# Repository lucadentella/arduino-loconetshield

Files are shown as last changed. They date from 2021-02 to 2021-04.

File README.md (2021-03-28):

# Loconet Shield / Interface
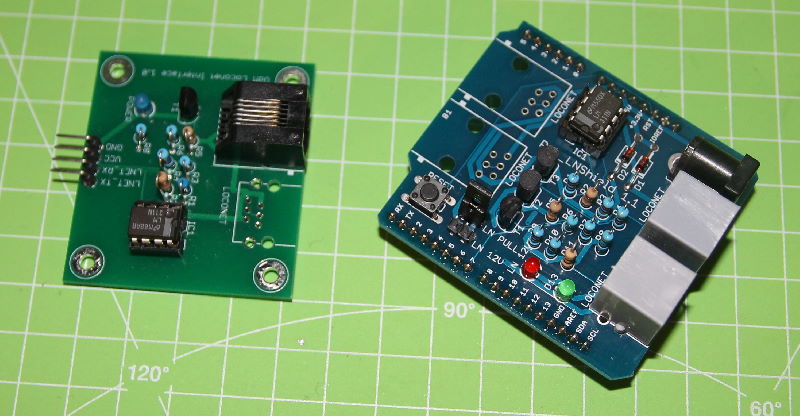
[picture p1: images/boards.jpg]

## Description
Interface to connect a 5V microcontroller to the Loconet bus.
Available as an Arduino shield or a stand-alone module.
A "master" version is also available, which implements power supply and bus termination.

*Interfaccia per collegare un microcontrollore a 5V al bus Loconet.
Disponibile sia come shield per Arduino che come modulo stand-alone.
E' disponibile anche una versione "master", che aggiunge le funzionalità di alimentazione e terminazione del bus.*
## Examples

In the Arduino folder, some basic sketches are provided to demonstrate the use of the interface. The [mrrwa/LocoNet](https://github.com/mrrwa/LocoNet) library is required (can be installed via Library Manager).

*Nella cartella Arduino, sono disponibili alcuni semplici sketch per dimostrare il funzionamento della interfaccia. E' richiesta la libreria [mrrwa/LocoNet](https://github.com/mrrwa/LocoNet) (può essere installata da Library Manager).*

## Documentation
- [Basic tutorial in  **English**](https://youtu.be/1dmCtpfb8J8)  (Youtube)
- [Tutorial base in  **Italiano**](https://youtu.be/m1i-pzcgra8)  (Youtube)
- [MasterInterface+Locobuffer tutorial in  **English**](https://youtu.be/BdRhHBKUpPE)  (Youtube)
- [Tutorial su InterfacciaMaster+Locobuffer in  **Italiano**](https://youtu.be/tLN5pXX8Gf4)  (Youtube)

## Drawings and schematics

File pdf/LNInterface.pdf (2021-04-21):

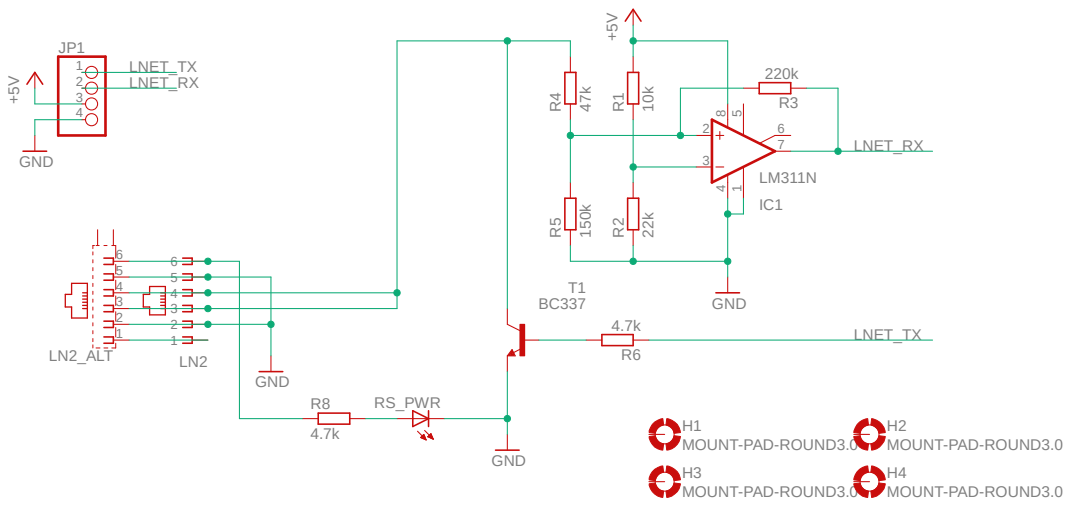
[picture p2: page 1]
LM311N ¹⁰k +5V; GND ²²k; GND; MOUNT-PAD-ROUND3.0; MOUNT-PAD-ROUND3.0 ⁶ ³²; R6 ¹²³⁴⁵⁶LN2; RS_PWR ¹²³⁴⁵⁶ LN2_ALT ¹²³⁴ JP1; LNET_RX; LNET_TX

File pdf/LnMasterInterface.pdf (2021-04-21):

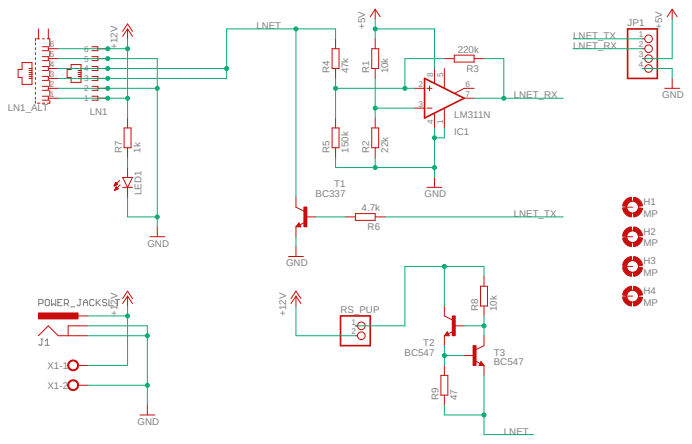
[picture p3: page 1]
LM311N ¹⁰k +5V; GND ²²k; GND; BC547 ⁺¹²V; R6 ¹²³⁴⁵⁶LN1; R⁸ R⁹ 12 RS_PUP ¹²³⁴⁵⁶ LN1_ALT; LED¹; LNET_RX; LNET; LNET_TX

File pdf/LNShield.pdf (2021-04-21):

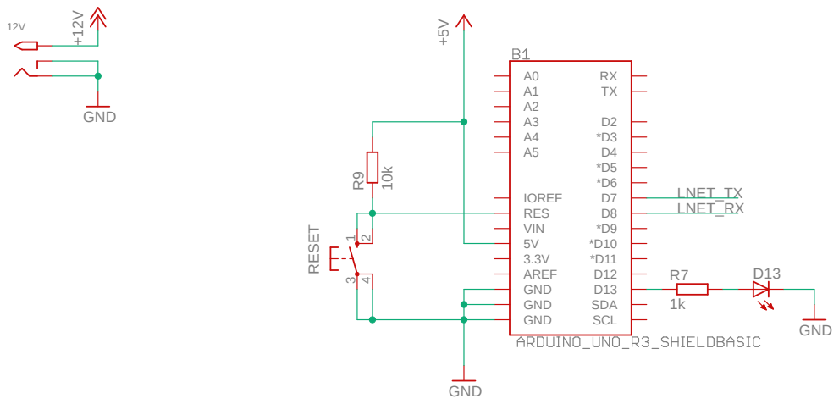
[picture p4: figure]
GND ⁺⁵V 10k; GND ⁺¹²V; GND; VIN; RES; AREF GND GND GND; IOREF; SDA; SCL R⁹ 3 12 4 RESET; LNET_RX; LNET_TX
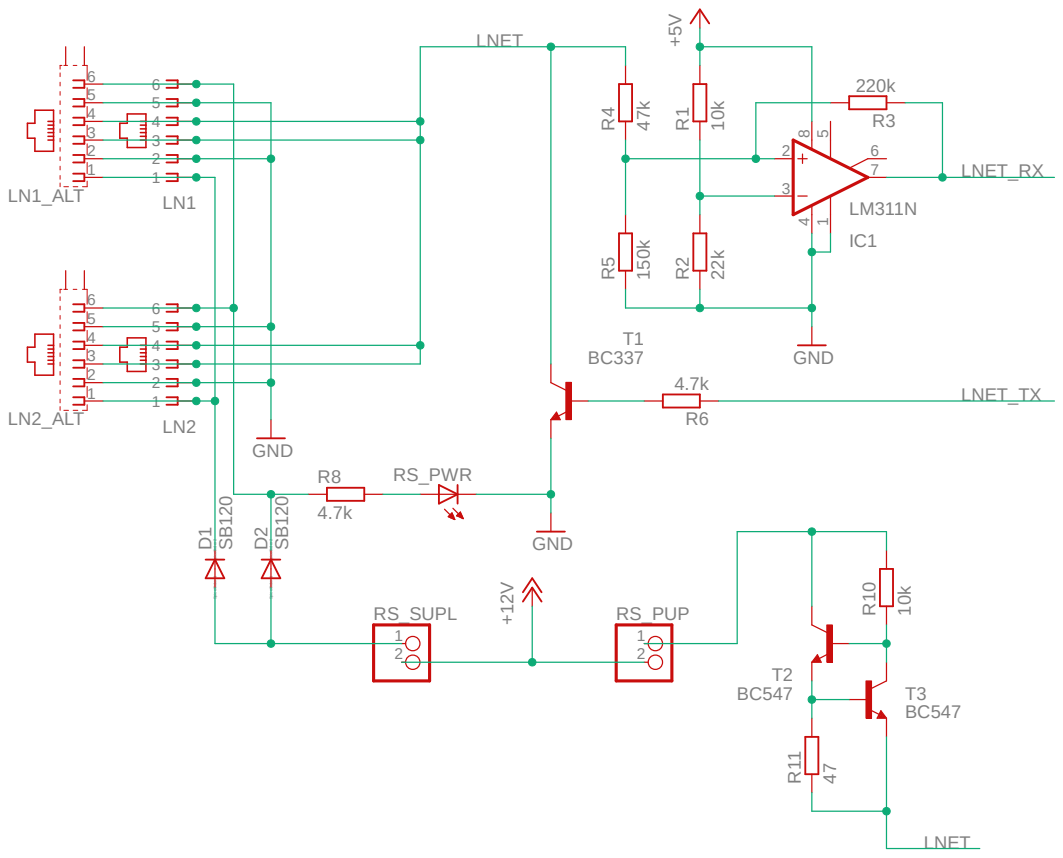
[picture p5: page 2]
LM311N ¹⁰k +5V; GND ²²k; GND; GND SB¹²⁰; SB¹²⁰; 2 RS_SUPL; RS_PWR; R¹⁰ R¹¹; 2 RS_PUP; 6 LN1_ALT; 6 LN2_ALT; LNET_RX; LNET; LNET_TX

SpiceOrder 1 SpiceOrder 2

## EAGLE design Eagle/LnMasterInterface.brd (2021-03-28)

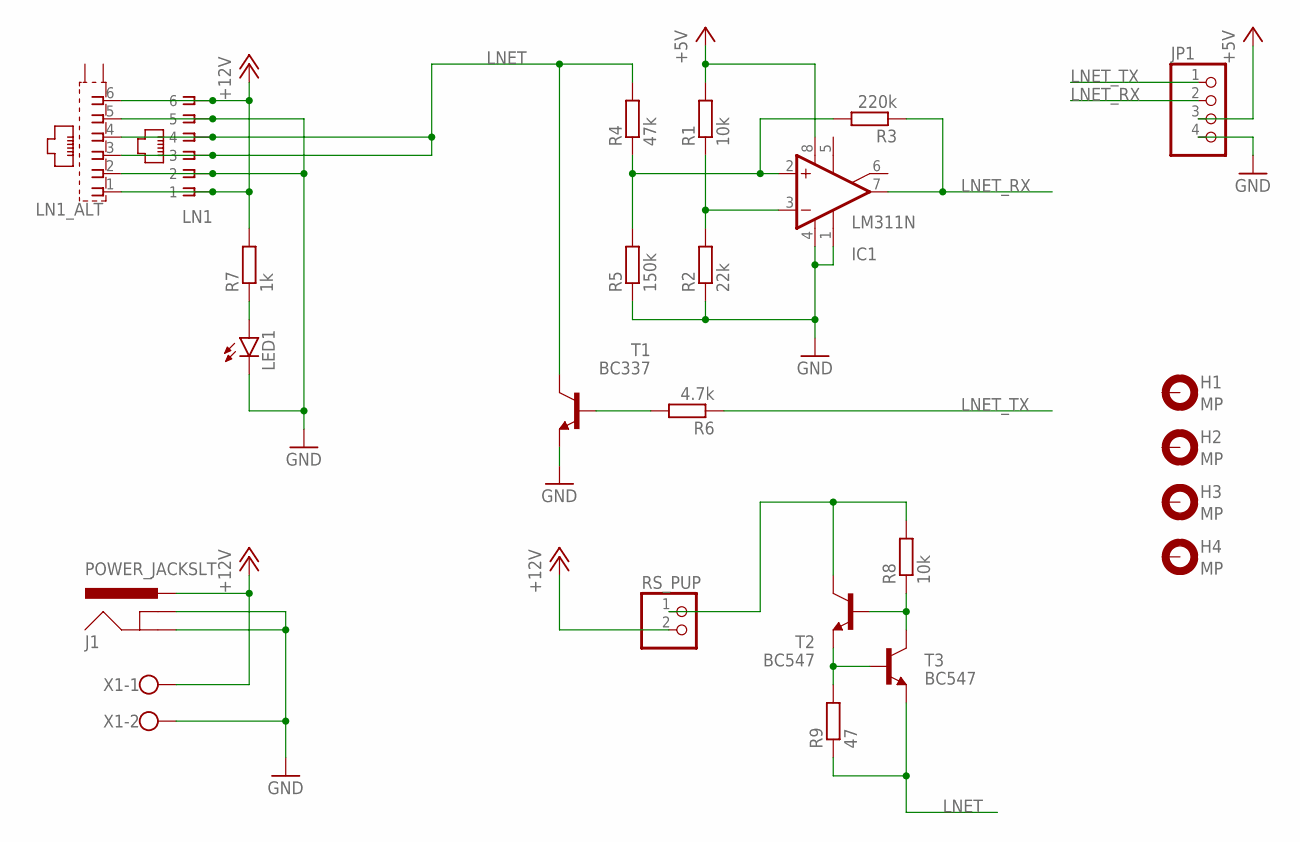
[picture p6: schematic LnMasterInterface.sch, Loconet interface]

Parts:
H1, H2, H3, H4: MP; 3,0-PAD
IC1: LM311N; DIL08
J1: POWER_JACKSLT; POWER_JACK_SLOT
JP1: PINHD-1X4; 1X04
LED1: LED3MM
LN1: RJ11-6X; RJ11-NO_SHIELD
LN1_ALT: YH-55-10
R1, R8: 10k; 0207/2V
R2: 22k; 0207/2V
R3: 220k; 0207/2V
R4: 47k; 0207/2V
R5: 150k; 0207/2V
R6: 4.7k; 0207/2V
R7: 1k; 0207/2V
R9: 47; 0207/2V
RS_PUP: PINHD-1X2; 1X02
T1: BC337; TO92
T2, T3: BC547; TO92
X1: W237-102

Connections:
+5V: IC1.8 (V+), JP1.3, R1.2
+12V: J1.PWR, LN1.1, LN1.6, LN1_ALT.1, LN1_ALT.6, R7.2, RS_PUP.2, X1.1
GND: IC1.1 (GND), IC1.4 (V-), J1.GND@1 (GNDBREAK), J1.GND@2 (GND), JP1.4, LED1.K (C), LN1.2, LN1.5, LN1_ALT.2, LN1_ALT.5, R2.1, R5.1, T1.1 (E), X1.2
LNET: LN1.3, LN1.4, LN1_ALT.3, LN1_ALT.4, R4.2, R9.1, T1.3 (C), T3.1 (E)
LNET_RX: IC1.7 (OUT), JP1.2, R3.1
LNET_TX: JP1.1, R6.1
unnamed: R6.2, T1.2 (B)
unnamed: LED1.A, R7.1
unnamed: IC1.3 (-IN), R1.1, R2.2
unnamed: IC1.2 (+IN), R3.2, R4.1, R5.2
unnamed: R9.2, T2.1 (E), T3.2 (B)
unnamed: R8.1, T2.2 (B), T3.3 (C)
unnamed: R8.2, RS_PUP.1, T2.3 (C)

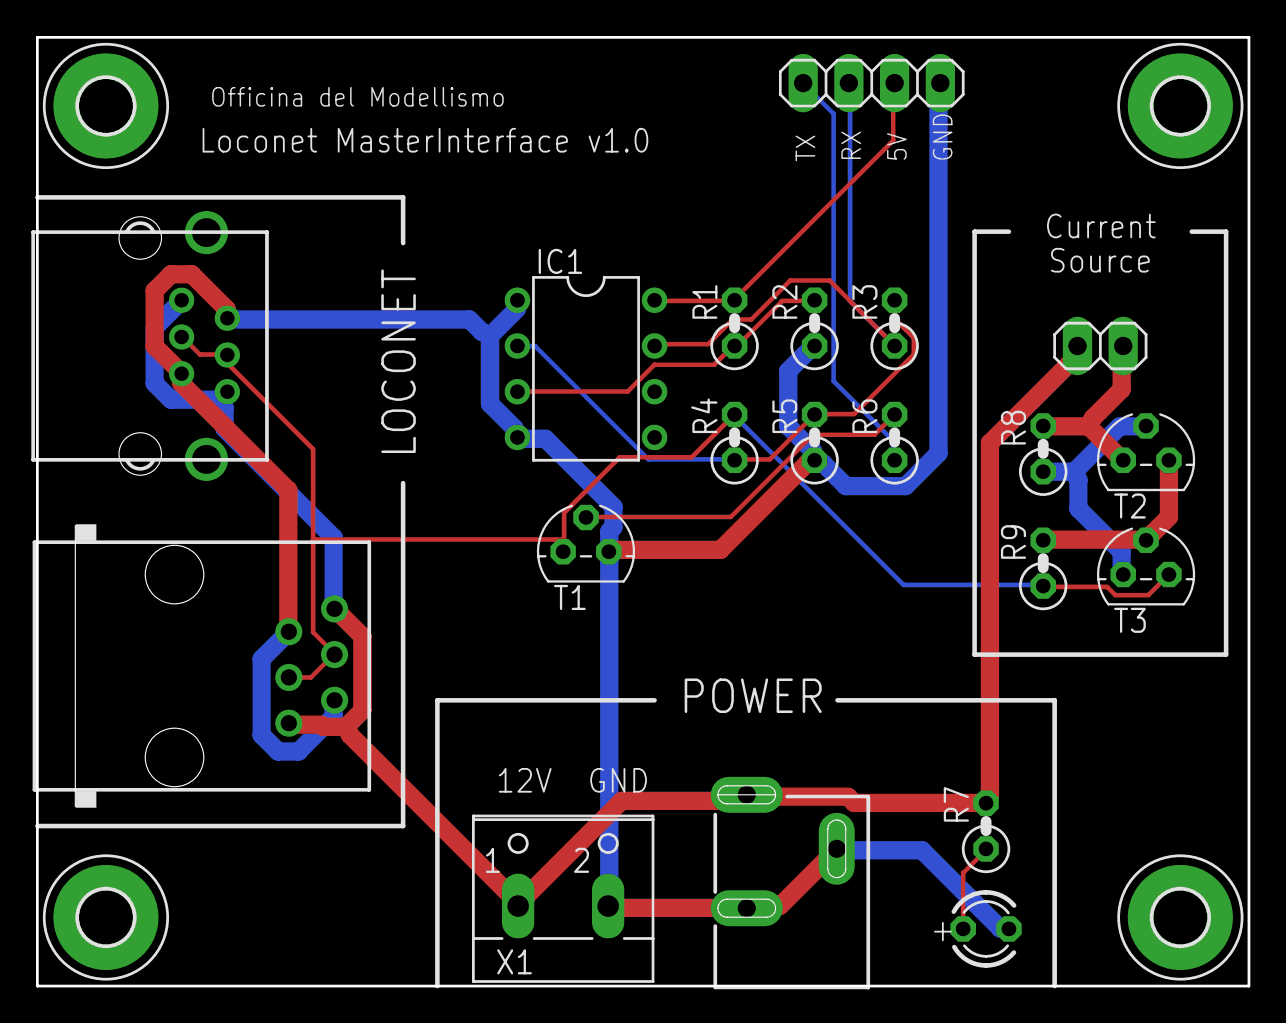
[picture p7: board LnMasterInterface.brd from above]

Board: 2 copper layers, 67.3 x 52.7 mm, 24 parts (0 on the bottom side), 13 nets.

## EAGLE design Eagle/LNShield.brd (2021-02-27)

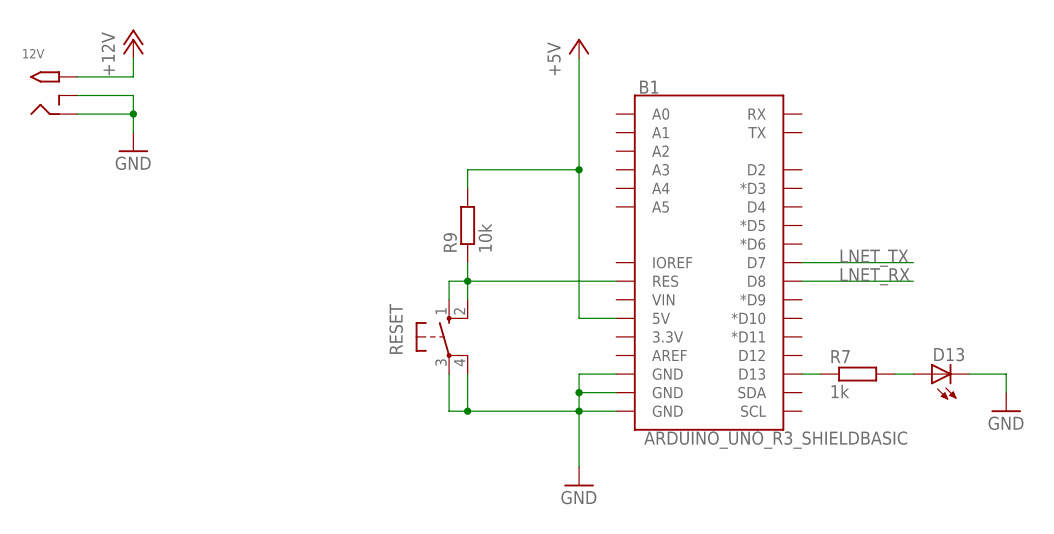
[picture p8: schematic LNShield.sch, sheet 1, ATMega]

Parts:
12V: 2.1MMJACKTHM; PJ-102A
B1: ARDUINO_UNO_R3_SHIELDBASIC; UNO_R3_SHIELD
D13: LED3MM
R7: 1k; 0207/2V
R9: 10k; 0207/2V
RESET: 10-XX; B3F-10XX

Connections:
+5V: B1.5V, R9.2; also elsewhere on the board
+12V: 12V.TIP; also elsewhere on the board
GND: 12V.RING, 12V.RING_SW, B1.GND@0 (GND), B1.GND@1 (GND), B1.GND@2 (GND), D13.K (C), RESET.3, RESET.4 (P1); also elsewhere on the board
LNET_RX: B1.D8; also elsewhere on the board
LNET_TX: B1.D7; also elsewhere on the board
unnamed: B1.D13, R7.1
unnamed: D13.A, R7.2
unnamed: B1.RES, R9.1, RESET.1 (S), RESET.2 (S1)

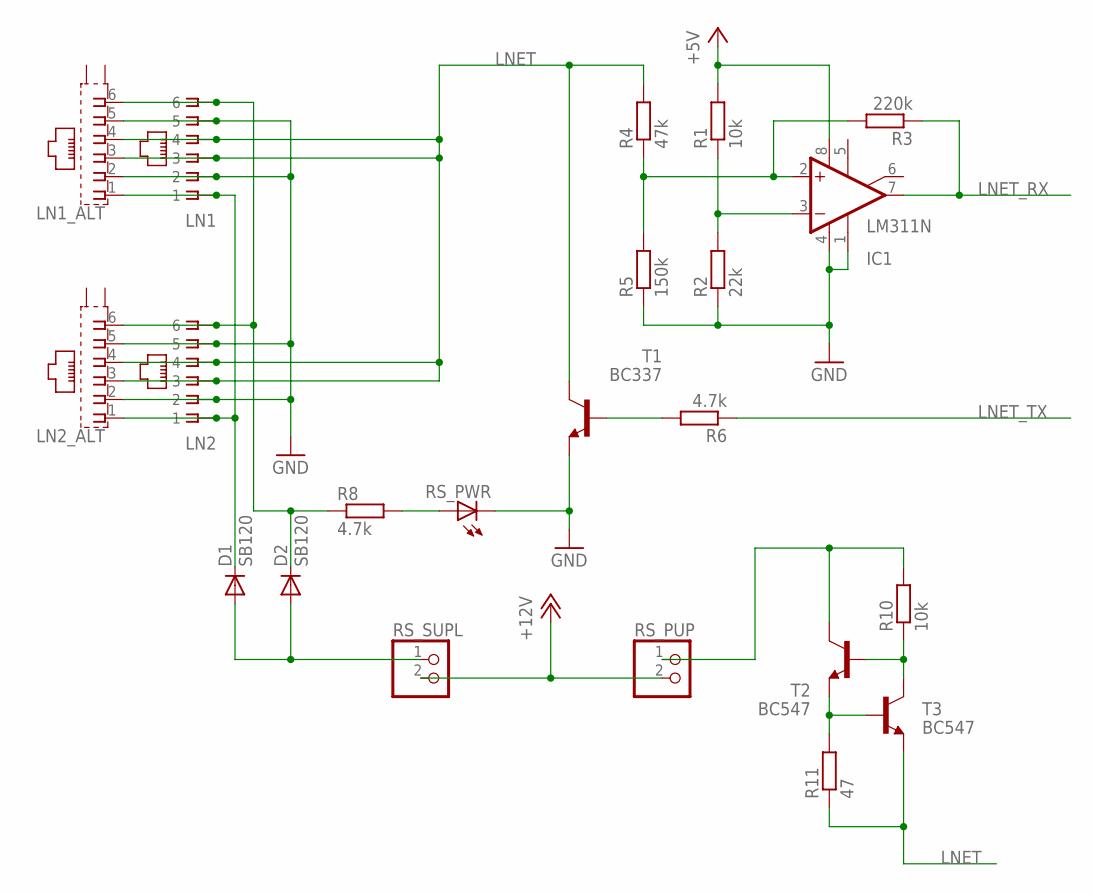
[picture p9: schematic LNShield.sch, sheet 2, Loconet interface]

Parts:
D1, D2: SB120; DO41-10
IC1: LM311N; DIL08
LN1, LN2: RJ11-6X; RJ11-NO_SHIELD
LN1_ALT, LN2_ALT: YH-55-10
R1, R10: 10k; 0207/2V
R2: 22k; 0207/2V
R3: 220k; 0207/2V
R4: 47k; 0207/2V
R5: 150k; 0207/2V
R6, R8: 4.7k; 0207/2V
R11: 47; 0207/2V
RS_PUP: PINHD-1X2; 1X02
RS_PWR: LED3MM
RS_SUPL: PINHD-1X2; 1X02
T1: BC337; TO92
T2, T3: BC547; TO92

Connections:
+5V: IC1.8 (V+), R1.2; also elsewhere on the board
+12V: RS_PUP.2, RS_SUPL.2; also elsewhere on the board
AA: D1.A, D2.A, RS_SUPL.1
GND: IC1.1 (GND), IC1.4 (V-), LN1.2, LN1.5, LN1_ALT.2, LN1_ALT.5, LN2.2, LN2.5, LN2_ALT.2, LN2_ALT.5, R2.1, R5.1, RS_PWR.K (C), T1.1 (E); also elsewhere on the board
LNET: LN1.3, LN1.4, LN1_ALT.3, LN1_ALT.4, LN2.3, LN2.4, LN2_ALT.3, LN2_ALT.4, R4.2, R11.1, T1.3 (C), T3.1 (E)
LNET_RX: IC1.7 (OUT), R3.1; also elsewhere on the board
LNET_TX: R6.1; also elsewhere on the board
unnamed: R6.2, T1.2 (B)
unnamed: IC1.3 (-IN), R1.1, R2.2
unnamed: IC1.2 (+IN), R3.2, R4.1, R5.2
unnamed: R11.2, T2.1 (E), T3.2 (B)
unnamed: R8.2, RS_PWR.A
unnamed: R10.1, T2.2 (B), T3.3 (C)
unnamed: R10.2, RS_PUP.1, T2.3 (C)
RAILSYNC_A: D2.C, LN1.6, LN1_ALT.6, LN2.6, LN2_ALT.6, R8.1
RAILSYNC_B: D1.C, LN1.1, LN1_ALT.1, LN2.1, LN2_ALT.1

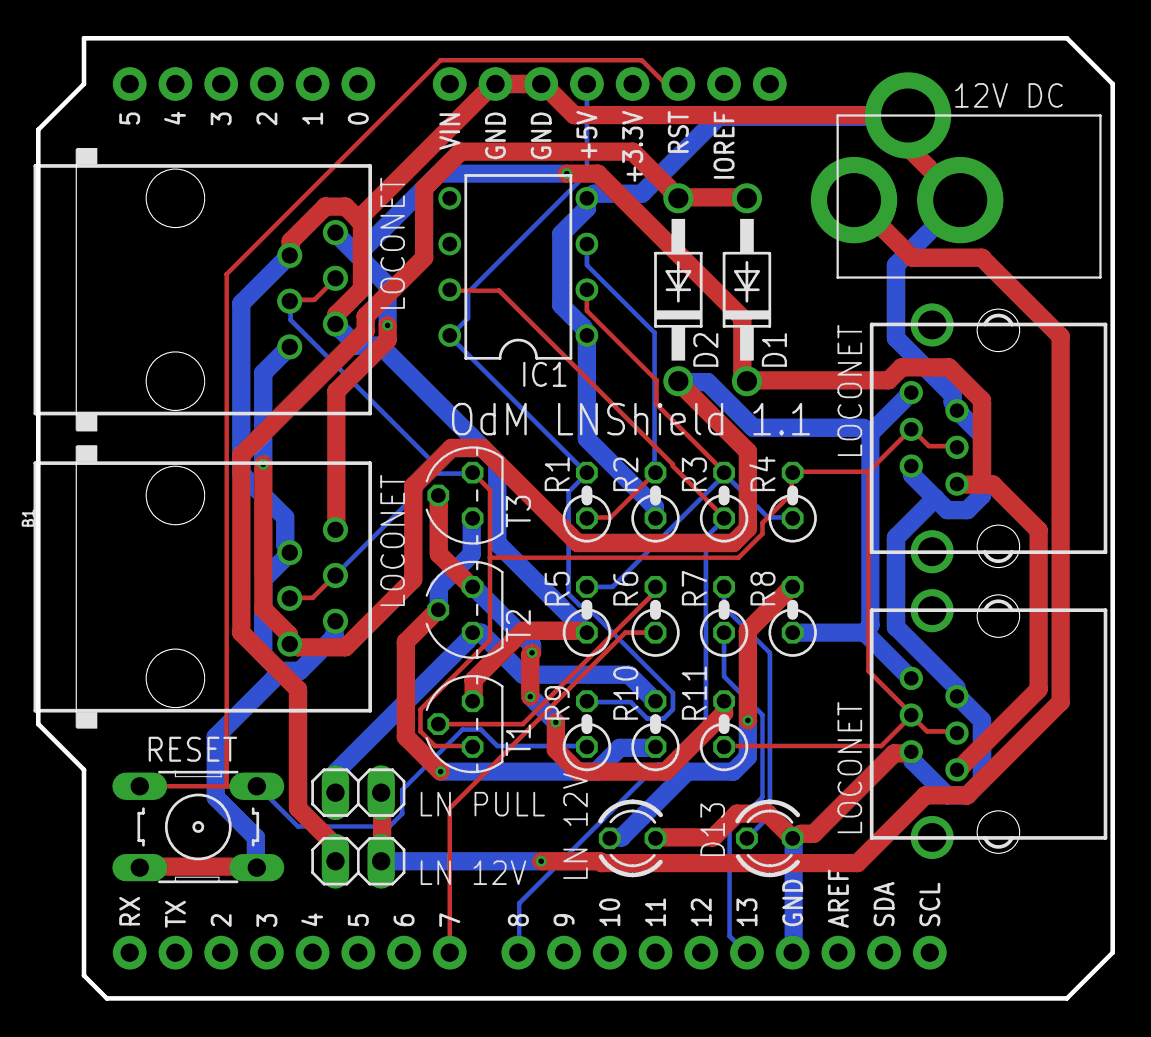
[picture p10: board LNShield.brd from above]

Board: 2 copper layers, 59.7 x 53.3 mm, 28 parts (0 on the bottom side), 19 nets.

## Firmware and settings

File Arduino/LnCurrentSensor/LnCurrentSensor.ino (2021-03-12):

// LnCurrentSensor v1.0
// 
// activates a Loconet sensor if current is detected by a CT (current transformer) sensor
// requires a CT sensor like DL-CT1005A connected to pin A0 

#include <LocoNet.h>

// address of the Loconet sensor
#define SENSOR_ADDRESS   2

// Sampling Parameters
const unsigned long sampleTime = 2000UL; 
const unsigned long numSamples = 100UL; 
const unsigned long sampleInterval = sampleTime / numSamples; 

bool sensorOn = false;

void setup() {

  Serial.begin(115200);
  Serial.println("LnCurrentSensor 1.0");
  Serial.println();
  
  // init Loconet library
  LocoNet.init();
  Serial.println("Init complete");
  Serial.println();
}

void loop() {

  float analogValue = readAvgValue(A0);

  if(analogValue > 0 && !sensorOn) {
    LocoNet.reportSensor(SENSOR_ADDRESS, 1);
    sensorOn = true;
    Serial.print("AnalogValue = ");
    Serial.print(analogValue);
    Serial.println(", reporting sensor ON");
  }
  
  if(analogValue == 0 && sensorOn) {
    LocoNet.reportSensor(SENSOR_ADDRESS, 0);
    sensorOn = false;
    Serial.print("AnalogValue = ");
    Serial.print(analogValue);
    Serial.println(", reporting sensor OFF");  
  }
}

float readAvgValue(int pin) {
  
  float accumulator = 0;
  unsigned int count = 0;
  unsigned long prevMicros = micros() - sampleInterval;
  
  while (count < numSamples) {
    if (micros() - prevMicros >= sampleInterval) {
      float adc_raw = (float) analogRead(pin);
      accumulator += adc_raw;
      count++;
      prevMicros += sampleInterval;
    }
  }

  float avg = (float)accumulator / (float)numSamples;
  return avg;  
}

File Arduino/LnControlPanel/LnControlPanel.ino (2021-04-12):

// Loconet Control Panel
// button connected to PIN 4, LEDs connected to PIN 2-3

#include <LocoNet.h>

#define BUTTON_PIN  4
#define ST_LED_PIN  2
#define DIV_LED_PIN 3

#define TURNOUT_ADDRESS 1

lnMsg *LnPacket;
int turnoutDirection;
bool buttonPressed = false;

void setup() {

  Serial.begin(115200);
  Serial.println("LnControlPanel");

  LocoNet.init();
  
  pinMode(BUTTON_PIN, INPUT_PULLUP);
  pinMode(ST_LED_PIN, OUTPUT);
  pinMode(DIV_LED_PIN, OUTPUT);

  // initial position, STRAIGHT
  turnoutDirection = 0;
  digitalWrite(ST_LED_PIN, HIGH);
  digitalWrite(DIV_LED_PIN, LOW);

  Serial.println("Init complete, ready to operate!");
}

void loop() {

  // process incoming Loconet messages
  LnPacket = LocoNet.receive();
  if(LnPacket) LocoNet.processSwitchSensorMessage(LnPacket);

  // button pressed
  if(digitalRead(BUTTON_PIN) == LOW && !buttonPressed) {

    if(turnoutDirection == 0) turnoutDirection = 1;
    else turnoutDirection = 0;
    LocoNet.requestSwitch(TURNOUT_ADDRESS, 0, turnoutDirection);
    buttonPressed = true;
  }

  // button released
  else if(digitalRead(BUTTON_PIN) == HIGH) buttonPressed = false;
}


void notifySwitchRequest( uint16_t Address, uint8_t Output, uint8_t Direction ) {
  
  if(Address == TURNOUT_ADDRESS) {

    turnoutDirection = Direction;
    if(turnoutDirection == 0) {
      digitalWrite(ST_LED_PIN, HIGH);
      digitalWrite(DIV_LED_PIN, LOW);
    } else {
      digitalWrite(ST_LED_PIN, LOW);
      digitalWrite(DIV_LED_PIN, HIGH);       
    }
  }
}

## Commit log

2021-03-12 Sensors added
2021-03-28 Master interface and Locobuffer firmware
    [LnMasterInterface.brd, LnMasterInterface.sch]
2021-04-21 Schematic in PDF format added

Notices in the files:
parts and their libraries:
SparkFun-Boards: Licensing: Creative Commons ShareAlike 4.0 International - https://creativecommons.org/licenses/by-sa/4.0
